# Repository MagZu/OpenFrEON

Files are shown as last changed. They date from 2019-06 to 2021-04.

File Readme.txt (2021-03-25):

The plan is to gradually promote adjustments:
1. Adjust the size of the buckle so that it can fit the gopro socket in the market. (Has been completed)
2. Add LeTV phone case. (During testing)
3. Adjust the structural defects of the mobile phone case. (under design)
4. Cancel the hardware. Use the wood structure to ensure the strength of the buckle. (To be started)

Shell introduction, hardware details and purchase link
http://www.openpilot.net/?thread-14.htm

In the folder
pedal
giraffe
leeco
oneplus
gopro
*old is officially owned by openfreon

All rights reserved by copyright owners

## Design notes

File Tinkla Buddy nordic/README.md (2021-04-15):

<h2>Print settings</h2>

layer height 0,2<br>
100% infill density<br>
Material: ABS<br>
Support: no<br>
<br>
I used wall thickness 1,5mm <br>
<br>
Feel free to ask me on discord (MagZu #3328) and I will share the project if you want to modify the case

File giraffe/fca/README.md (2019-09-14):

FCA (Fiat Chrysler Automotive) Giraffe
====

Get your panda deeper into your:

- 2017 Chrysler Pacifica Hybrid

May fit other FCA cars as well.

The switches
====

The 2 DIP switches control signals to the stock ADAS system

- 1 -- IGN to camera

- 2 -- ADAS CAN1 -> camera CAN (OBDII pins 12 & 13)



Initial design from the community from: [@adhintz](https://github.com/adhintz)

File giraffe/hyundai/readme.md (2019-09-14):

Hyundai giraffe
====

Get your panda deeper into your compatible Hyundai vehicle. Built with pinout for our Hyundai Sante Fe. May work with other Hyundai/Kia, check EWD for verification. 

The switches
====

The 4 DIP switches control signals to the stock ADAS system

- 1 -- ADAS CAN1 -> main body CAN

- 2 -- ADAS CAN1 -> panda CAN3 (OBDII pins 12 & 13)

- 3 -- IGNITION POWER -> panda power

- 4 -- ADAS power & ignition -> power & ignition

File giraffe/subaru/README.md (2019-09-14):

Subaru giraffe
====

Get your panda deeper into your Subaru Impreza
May work with other cars with the same connector

====

All switching between stock ADAS on and Stock ADAS off is done via a relay

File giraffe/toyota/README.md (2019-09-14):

Toyota giraffe
====

Get your panda deeper into your compatible Toyota vehicle

The switches
====



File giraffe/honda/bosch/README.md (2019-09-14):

Honda giraffe (Bosch ADAS)
====

Get your panda deeper into your:

- 2017+ Honda CR-V
- 2017+ Honda Civic Hatchback
- 2018+ Honda Accord

May fit other Hondas with Bosch hardware as well.

The switches
====

The 2 DIP switches control signals to the stock ADAS system

- 1 -- IGN to camera

- 2 -- ADAS CAN2 -> camera CAN (OBDII pins 12 & 13)



Initial design from the community from: [@csouers](https://github.com/csouers), [@energee](https://github.com/energee), and Alaric Egli

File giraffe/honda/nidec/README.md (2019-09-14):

Honda giraffe
====

Get your panda deeper into your Honda Civic or Acura ILX

The switches
====

The 4 DIP switches control signals to the stock ADAS system

- 1 -- ADAS CAN1 -> main body CAN

- 2 -- ADAS CAN1 -> panda CAN3 (OBDII pins 12 & 13)

- 3 -- ADAS CAN2 -> radar CAN

- 4 -- ADAS power & ignition -> power & ignition



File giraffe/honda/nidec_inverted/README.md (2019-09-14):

Honda Inverted Giraffe
====

Get your panda deeper into your Odyssey, 2019 Honda Pilot, TLX and probably other cars with an "inverted" connector

The switches
====

The 4 DIP switches control signals to the stock ADAS system

- 1 -- ADAS CAN1 -> main body CAN

- 2 -- ADAS CAN1 -> panda CAN3 (OBDII pins 12 & 13)

- 3 -- ADAS CAN2 -> radar CAN

- 4 -- ADAS power & ignition -> power & ignition



Thanks to [@csouers](https://github.com/csouers) and [@energee](https://github.com/energee) for their input on this design

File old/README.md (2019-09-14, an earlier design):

# OpenFrEON 2.0

This project is for the purpose of creating a device similar to Comma.ai's [EON DevKit](https://comma.ai/shop/products/eon-gold-dashcam-devkit/?ref=4). 

If you don't already have an EON DevKit, you can buy one here: [https://comma.ai/shop/products/eon-gold-dashcam-devkit](https://comma.ai/shop/products/eon-gold-dashcam-devkit/?ref=4)

Note: These components are designed to fit the dimensions the One Plus 3T smartphone. Other devices will not be compatible. 

FrEON2.0 Front
FrEON2.0 Back

# Printable—Included Parts

- FrEON2.stl (All parts for standard FrEON 2.0)

- FrEON2EM.stl (All parts for FrEON 2.0 modded for 140mm heatsink

**FrEON2-Components**

- FrEON2-Left.stl

- FrEON2-Right.stl

- FrEON2-FanDuct.stl

- FrEON2-BottomClip.stl

**FrEON2EM-Components (for 140mm heatsink)**

- FrEON2-Left.stl

- FrEON2-Right.stl

- FrEON2-BottomClip.stl

**Mounts**

- includes FrEON mounts from 20-40 degrees in increments of 2 degrees. 

# Non-Printable Parts & Hardware

- [4 x M3x10mm Screws](https://www.amazon.com/Uxcell-a16022300ux0165-M3x10mm-Socket-Countersunk/dp/B01DIL1KDS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)

- [4 x Heat Set Inserts](https://www.amazon.com/Uxcell-a16041800ux0824-Knurled-Threaded-Embedment/dp/B01IYWTCWW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)

- [100x60x10mm Heatsink](https://www.amazon.com/Heatsink-TOOGOO-Aluminum-Radiator-100x60x10mm/dp/B01EJ1CYB8) _(The Heatsink included with the EON **Dashcam Devkit** is milled to accommodate the camera lens.)_

- [40x10mm 5V Blower](https://www.digikey.com/product-detail/en/delta-electronics/BFB0405HHA-A/603-1113-ND/1014444) 

- [3M GoPro Mount](https://www.amazon.com/dp/B00BUD6LPY) 

# Support

If you have any questions regarding development or issues with the current design, find me on [Discord](https://discord.comma.ai/) _@Chase_

Help fund this project and future projects by donating via paypal: https://paypal.me/chasehiggins/

Or support me on patreon: https://www.patreon.com/chasehiggins/

Support Comma.ai and myself by buying an EON using my affiliate link: https://comma.ai/shop/?ref=4

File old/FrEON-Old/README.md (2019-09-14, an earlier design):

# OpenFrEON

Open Source parts to replace broken or damaged pieces on your existing **EON Dashcam DevKit** from [Comma.ai](http://comma.ai).

If you don't already have an EON Dashcam DevKit, you can buy one here: [https://comma.ai/shop/products/eon-dashcam-devkit/](https://comma.ai/shop/products/eon-dashcam-devkit/?ref=4)

FrEON

# Printable—Included Parts

- FrEON Body Left

- FrEON Body Right

- FrEON Bottom Clip

- FrEON Fan Cover Grill

- Fake Heatsink

# Printable—not-included Parts

The only printed pieces not included in this repository are the various degree mounting clips—these parts can be found on [Comma.ai's GitHub](https://github.com/commaai/neo/tree/master/case/eon). 

# Non-Printable Parts & Hardware

- [8 x M3x6mm screws](https://www.amazon.com/dp/B079821FCN/ref=twister_B079838C8T?_encoding=UTF8&psc=1)

- [8 x M3 Nuts](https://www.amazon.com/Shapenty-100PCS-Stainless-Female-Fastener/dp/B071NLDW56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)

- [100x60x10mm Heatsink](https://www.amazon.com/Heatsink-TOOGOO-Aluminum-Radiator-100x60x10mm/dp/B01EJ1CYB8) _(The Heatsink included with the EON **Dashcam Devkit** is milled to accommodate the camera lens.)_

- [40x10mm 5V Blower](https://www.digikey.com/product-detail/en/delta-electronics/BFB0405HHA-A/603-1113-ND/1014444) 

- [3M GoPro Mount](https://www.amazon.com/dp/B00BUD6LPY) 

# ToDo

- [x] Design _Left_ and _Right_ portions of FrEON housing

- [x] Design Bottom Clip

- [x] Compile a list of parts and pieces

- [x] Design Fan Cover

- [ ] Accommodate space for EON Board

- [ ] Peltier Version

- [ ] Custom FrEON Board

# Support

If you have any questions regarding development or issues with the current design, find me on [Slack](comma.slack.com) _@Chase_

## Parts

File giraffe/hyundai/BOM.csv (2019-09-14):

Ref Des | Package | Manufacturer PN | Qty | Link
U1 | 12-Pin | MG645845 | 1 | https://chcwld.en.alibaba.com/product/60784996669-801836231/KET_020_12M_Automotive_cable_connector_Electronic_Connector.html
U2 | 12-Pin | MG655794 | 1 | https://chcwld.en.alibaba.com/product/60784830234-801836231/KET_020_12F_Automotive_cable_connector_Electronic_Connector.html
 |  | ST731407-3 | 12
J1 | 16-pin | OBDII-FEMALE | 1 | https://cn1514770021qfbj.en.alibaba.com/product/60598699808-804284542/J1962F_OBD2_16_Pin_Female_connector_OBD2_Socket.html
J2 | RJ45-RA | A-2004-2-4-LPS-N-R | 1 | https://www.digikey.com/product-detail/en/assmann-wsw-components/A-2004-2-4-LPS-N-R/AE10387-ND/2183638
J3 | 3-pin | EJ508A | 1 | https://www.digikey.com/products/en?keywords=ej508a
SW1 | SMD | 204-214ST | 1 | https://www.digikey.com/scripts/DkSearch/dksus.dll?Detail&itemSeq=238874105&uq=636415194298612120
R1 | 0603-R | ERJ-PA3J121V | 1 | https://www.digikey.com/product-detail/en/panasonic-electronic-components/ERJ-PA3J121V/P120BZCT-ND/5036246

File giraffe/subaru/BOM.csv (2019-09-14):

Comma Access Point
Ref Des | Package | Manufacture PN | Qty | Link
J1 | 26 Pin R/A | 5018762640 | 1 | https://www.digikey.com/product-detail/en/molex/501876-2640/WM6091-ND/1787792
J2 | 10 Pin R/A | 5018761040 | 1 | https://www.digikey.com/products/en?keywords=501876-1040
J3 | 2 Pin R/A | 3-794618-2 | 1 | https://www.digikey.com/product-detail/en/te-connectivity-amp-connectors/3-794618-2/A33252-ND/1114990
R1 | DNP | DNP | DNP
R2 | R0402 | ERJ-2GEJ121X | 1 | https://www.digikey.com/product-detail/en/panasonic-electronic-components/ERJ-2GEJ121X/P120JCT-ND/146744
R4 | R0402 | ERJ-2GE0R00X | 1 | https://www.digikey.com/product-detail/en/panasonic-electronic-components/ERJ-2GEJ121X/P120JCT-ND/146744
C1 | DNP | DNP | DNP
S1 |  | G6S-2G DC12 | 1 | https://www.digikey.com/product-detail/en/omron-electronics-inc-emc-div/G6S-2G-DC12/Z892-ND/20450
D1,D2 | SMD | ES2BA-13-F | 1 | https://www.digikey.com/product-detail/en/diodes-incorporated/ES2BA-13-F/ES2BA-FDICT-ND/815690
Panda Interface Point
Ref Des | Package | Manufacture PN | Qty | Link
J1 | OBDII |  | 1 | https://cn1514770021qfbj.en.alibaba.com/product/60598699808-804284542/J1962F_OBD2_16_Pin_Female_connector_OBD2_Socket.html
J2 | RJ45 R/A | A-2004-2-4-LPS-N-R | 1 | https://www.digikey.com/product-detail/en/assmann-wsw-components/A-2004-2-4-LPS-N-R/AE10387-ND/2183638
J3 | 10 Pin R/A | 5018761040 | 1 | https://www.digikey.com/products/en?keywords=501876-1040
Wiring Harness
Ref Des | Package | Manufacture PN | Qty | Link
 | 10 Pin Female | 5016461000 | 2 | https://www.digikey.com/product-detail/en/molex/5016461000/WM6058-ND/1787759
 | 26 Pin Female | 5016462600 | 1 | https://www.digikey.com/short/ppwt0m
 | Molex Crimp Pins | 5016471000 | 44 | https://www.digikey.com/product-detail/en/molex/5016471000/WM6057CT-ND/1787797
 | 16 Pin Male | 1565476-1 | 1 | https://www.mouser.com/ProductDetail/TE-Connectivity/1565476-1
 | 16 Pin Female | 1318386-1 | 1 | https://www.digikey.com/product-detail/en/te-connectivity-amp-connectors/1318386-1/A106550-ND/2273493
 | TE Connectivity crimp pins | 1123343-1 | 24 | https://www.digikey.com/product-detail/en/te-connectivity-amp-connectors/1123343-1/A107011CT-ND/3488572

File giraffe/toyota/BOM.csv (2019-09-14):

Ref Des | Package | Manufacturer PN | Qty | Link
J1 | 12-pin | 1318774-1 | 1 | http://www.mouser.com/Search/ProductDetail.aspx?R=1318774-1virtualkey57100000virtualkey571-1318774-1
J2 | 12-pin-RA | 1318772-2 | 1 | http://www.mouser.com/Search/ProductDetail.aspx?R=1318772-2virtualkey57100000virtualkey571-1318772-2
 |  | 1123343-1 | 12 | https://www.digikey.com/product-detail/en/te-connectivity-amp-connectors/1123343-1/A107011CT-ND/3488572
 |  | PRPC040SAAN-RC | 1 | https://www.digikey.com/products/en?keywords=S1011EC-40-ND
J3 | 16-pin | OBDII-FEMALE | 1 | https://cn1514770021qfbj.en.alibaba.com/product/60598699808-804284542/J1962F_OBD2_16_Pin_Female_connector_OBD2_Socket.html
J4 | RJ45-RA | A-2004-2-4-LPS-N-R | 1 | https://www.digikey.com/product-detail/en/assmann-wsw-components/A-2004-2-4-LPS-N-R/AE10387-ND/2183638
J5 | 3-pin | EJ508A | 1 | https://www.digikey.com/products/en?keywords=ej508a
SW1 | SMD | 204-214ST | 1 | https://www.digikey.com/scripts/DkSearch/dksus.dll?Detail&itemSeq=238874105&uq=636415194298612120
R1 | 0603 | ERJ-PA3F1200V | 1 | https://www.digikey.com/short/p47rhj
SCREWs | Phillips | 92010A118 | 2 | https://www.mcmaster.com/#catalog/92010A118

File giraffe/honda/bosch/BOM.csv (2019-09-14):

Ref Des | Package | MPN | Qty | Link
J3 | 12-pin | OBDII-FEMALE | 1 | https://www.alibaba.com/product-detail/J1962F-OBD2-OBD-2-16-Pin_60657250485.html
SW1 | SMD | CT204212ST-ND | 1 | https://www.digikey.com/products/en?mpart=204-212ST&v=119
J1 | 3-pin | EJ508A-ND | 1 | https://www.digikey.com/products/en?keywords=ej508a
J4 | RJ45-VERT | AE10399-ND | 1 | https://www.digikey.com/scripts/DkSearch/dksus.dll?Detail&itemSeq=265472924&uq=636662223909317983
J5 | 12 Pin | M34S75C4F1 | 12 | https://www.digikey.com/product-detail/en/jae-electronics/M34S75C4F1/670-2268-2-ND/2044176
J2 | 12 Pin | S1211EC-40-ND | 12 | https://www.digikey.com/product-detail/en/sullins-connector-solutions/PRPC040SFAN-RC/S1211EC-40-ND/2775334
D1 | SMD | ES2BA-13-F | 1 | https://www.digikey.com/product-detail/en/diodes-incorporated/ES2BA-13-F/ES2BA-FDICT-ND/815690
M3 8mm | Hex | 91294A132 | 1 | https://www.mcmaster.com/#91294A128
M3 14 mm | Hex | 91294A128 | 2 | https://www.mcmaster.com/#91294A133
Nut | Hex | 91828A211 | 2 | https://www.mcmaster.com/#catalog/124/3276/=1doa85x

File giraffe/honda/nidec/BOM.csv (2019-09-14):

Ref Des | Package | Manufacturer PN | Qty | Link
J1 | 20-pin-RA | MX34020NF1 | 1 | https://www.digikey.com/product-detail/en/jae-electronics/MX34020NF1/670-2924-ND/2139260
J2 | 20-pin | MX34020SF1 | 1 | https://www.digikey.com/scripts/DkSearch/dksus.dll?Detail&itemSeq=238973409&uq=636415194298622122
 |  | M34S75C4F1 | 20 | https://www.digikey.com/product-detail/en/jae-electronics/M34S75C4F1/670-2268-1-ND/2044290
 |  | PRPC040SAAN-RC | 1 | https://www.digikey.com/products/en?keywords=S1011EC-40-ND
J3 | 16-pin | OBDII-FEMALE | 1 | https://cn1514770021qfbj.en.alibaba.com/product/60598699808-804284542/J1962F_OBD2_16_Pin_Female_connector_OBD2_Socket.html
J4 | RJ45-VERT | A-2014-2-4-LP/FS-R | 1 | https://www.digikey.com/scripts/DkSearch/dksus.dll?Detail&itemSeq=238773681&uq=636415194298592116
SW1 | SMD | 204-214ST | 1 | https://www.digikey.com/scripts/DkSearch/dksus.dll?Detail&itemSeq=238874105&uq=636415194298612120
SCREWs | Phillips | 92010A118 | 2 | https://www.mcmaster.com/#catalog/92010A118

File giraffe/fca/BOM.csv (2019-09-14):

Ref Des | Package | MPN | Qty | Link
J1 | 3-pin | RASM722PX | 1 | https://www.digikey.com/products/en?keywords=RASM722PX
J2 | OBDII | J1962F | 1 | https://www.alibaba.com/product-detail/J1962F-OBD2-OBD-2-16-Pin_60657250485.html
J3 | RJ45-RA | A-2004-2-4-LPS-N-R | 1 | https://www.digikey.com/product-detail/en/assmann-wsw-components/A-2004-2-4-LPS-N-R/AE10387-ND/2183638
J4 | CONN HEADER VERT | 348250124 | 1 | https://www.digikey.com/product-detail/en/0348250124/WM10326-ND/4504599/?itemSeq=281019679
J5 | MINI50 CONN RCPT | 348240124 | 1 | https://www.digikey.com/product-detail/en/molex-llc/0348240124/WM10324-ND/4504597
SW1 | SMD | CT204212ST-ND | 1 | https://www.digikey.com/products/en?mpart=204-212ST&v=119
D1 | SMD | ES2BA-13-F | 1 | https://www.digikey.com/product-detail/en/diodes-incorporated/ES2BA-13-F/ES2BA-FDICT-ND/815690
R1 | 0603R | ERJ-PA3J121V | 1 | https://www.digikey.com/product-detail/en/panasonic-electronic-components/ERJ-PA3J121V/P120BZCT-ND/5036246
Crimps |  | 5600230421 | 12 | https://www.digikey.com/product-detail/en/molex-llc/5600230421/WM8745CT-ND/3178491
Pins | S1011EC-40-ND |  | 12 | https://www.digikey.com/products/en?keywords=S1011EC-40-ND

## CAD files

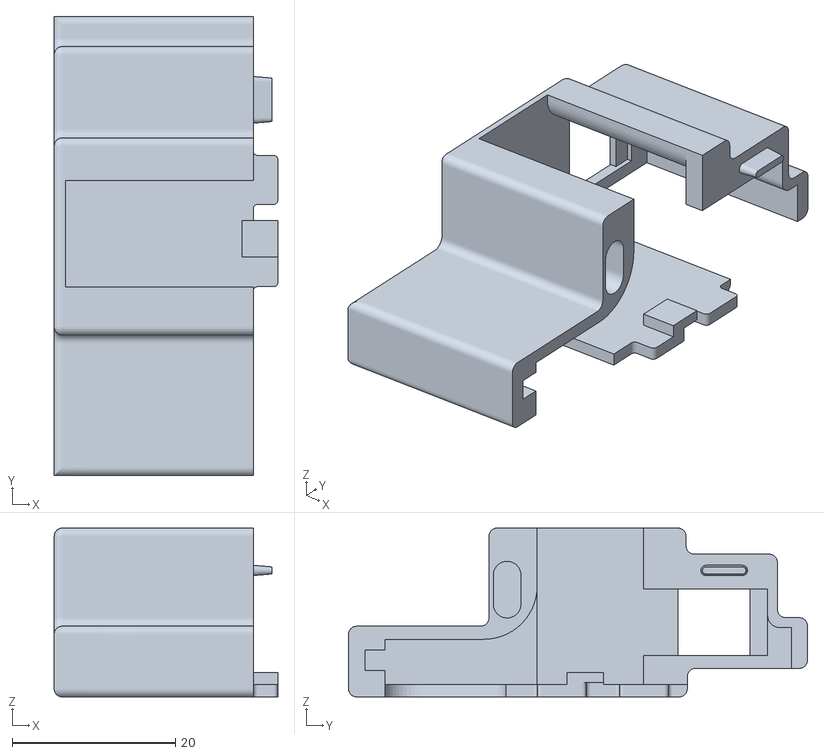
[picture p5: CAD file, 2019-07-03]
giraffe/fca/Giraffe_left.stl
27.4 x 56.2 x 20.7

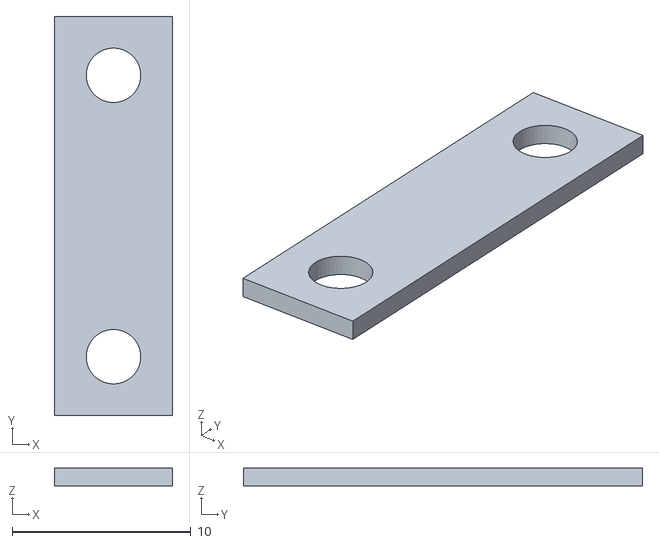
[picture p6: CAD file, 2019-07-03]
giraffe/ford/mechanical/giraffe_ford_spacer.stl
6.60 x 22.4 x 1.00

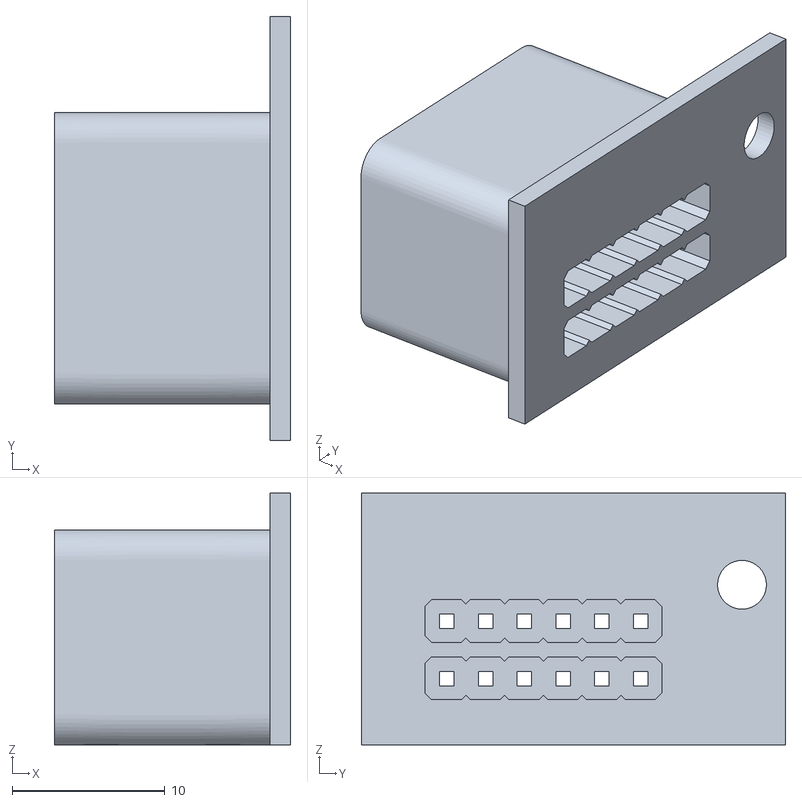
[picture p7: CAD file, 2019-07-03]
giraffe/honda/bosch/bosch_female_connector.stl
15.5 x 27.8 x 16.5

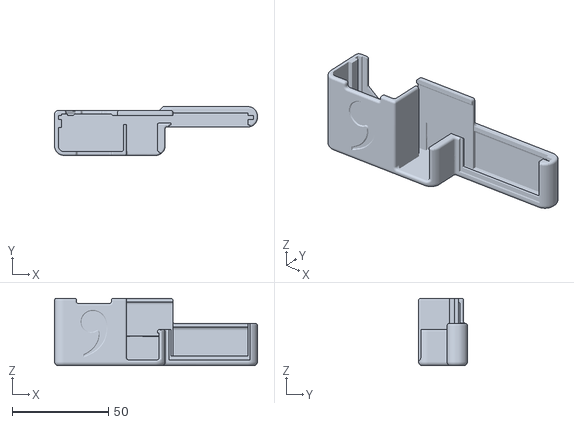
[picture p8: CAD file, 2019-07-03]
giraffe/honda/nidec/case.stl
105.5 x 25.4 x 35.0

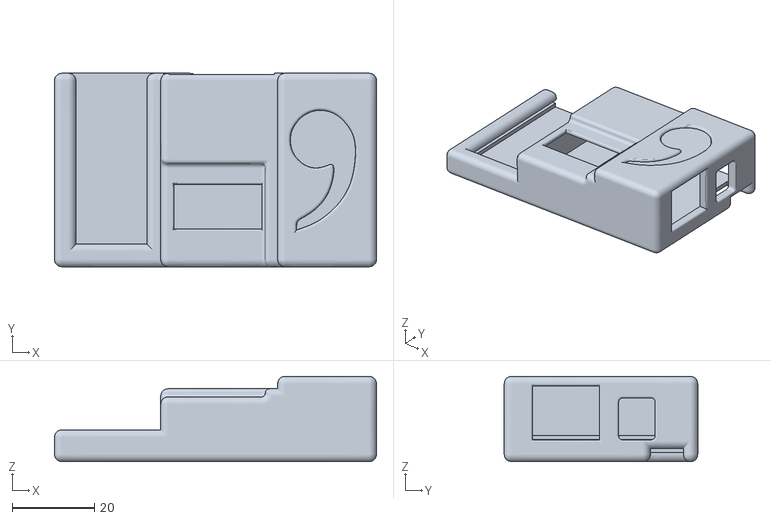
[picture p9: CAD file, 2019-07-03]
giraffe/hyundai/Hyundai_Giraffe.stl
78.2 x 47.0 x 20.7

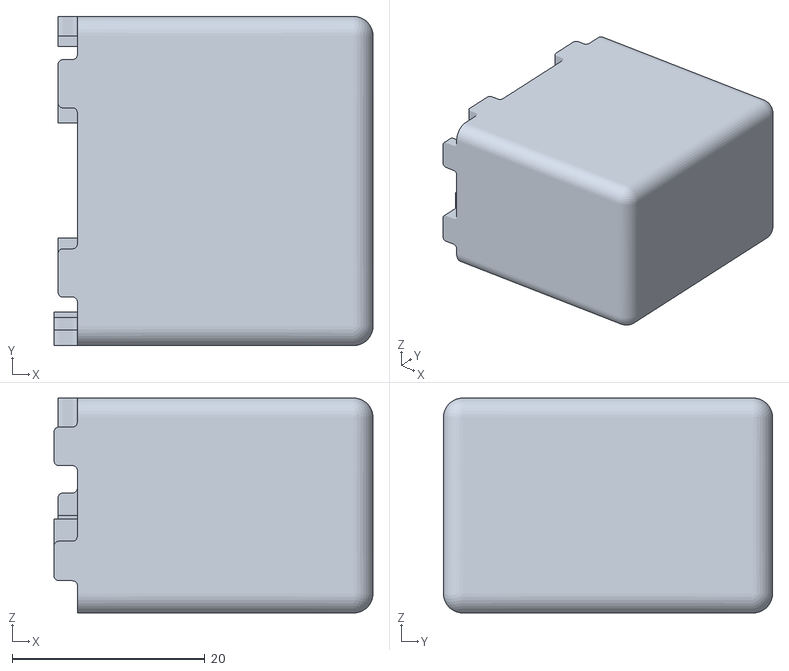
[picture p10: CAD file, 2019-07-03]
giraffe/subaru/PIP_right.stl
33.1 x 34.1 x 22.3

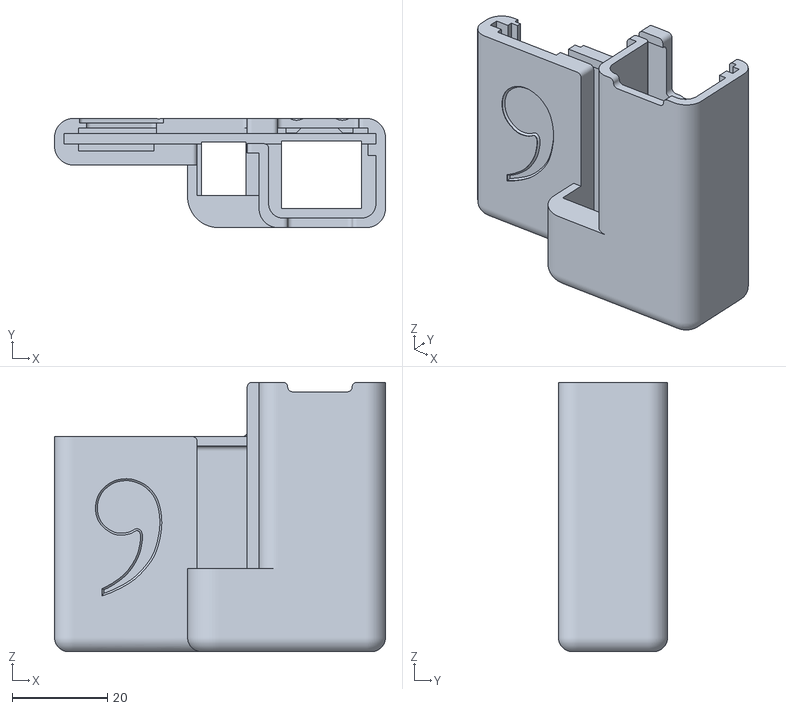
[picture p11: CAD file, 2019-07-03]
giraffe/toyota/case.stl
69.4 x 22.9 x 56.5

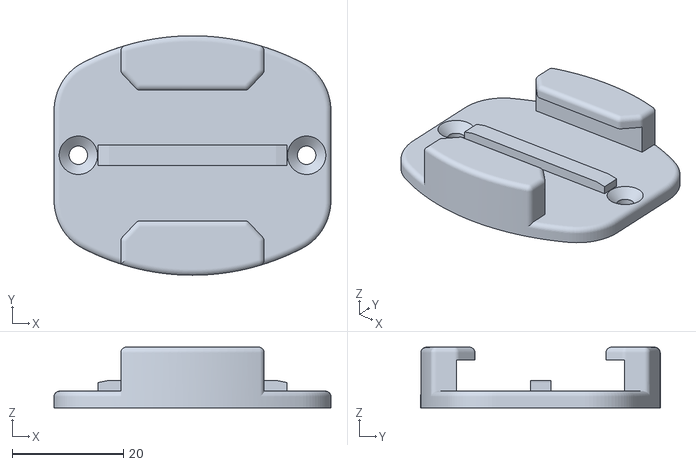
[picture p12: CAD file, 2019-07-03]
gopro mount/gopro.STL
49.8 x 43.0 x 10.9

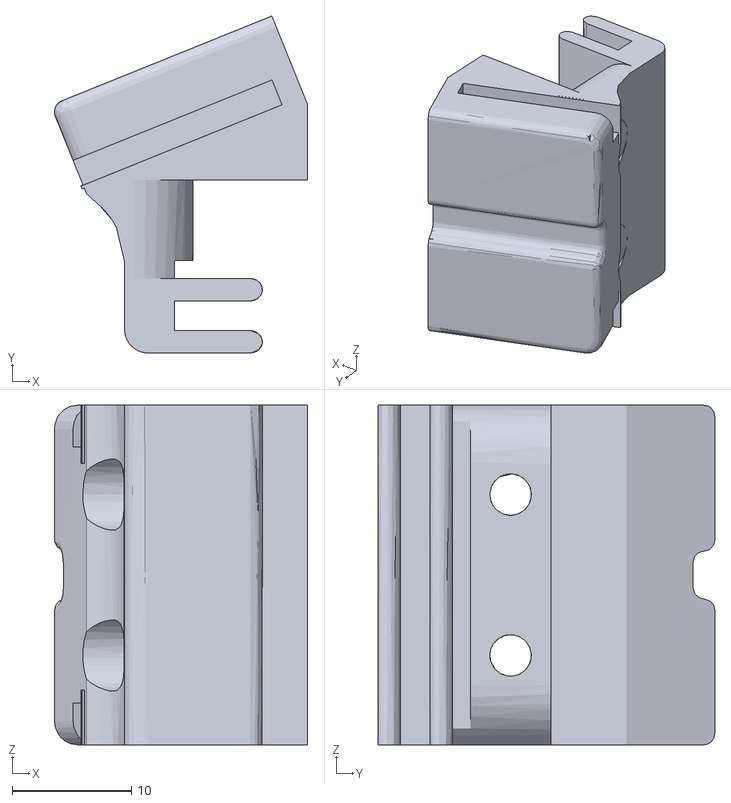
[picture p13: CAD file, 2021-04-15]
leeco lepro3 x720/Tesla mount 22D_2.15mm_slot.stl
21.2 x 28.3 x 28.5

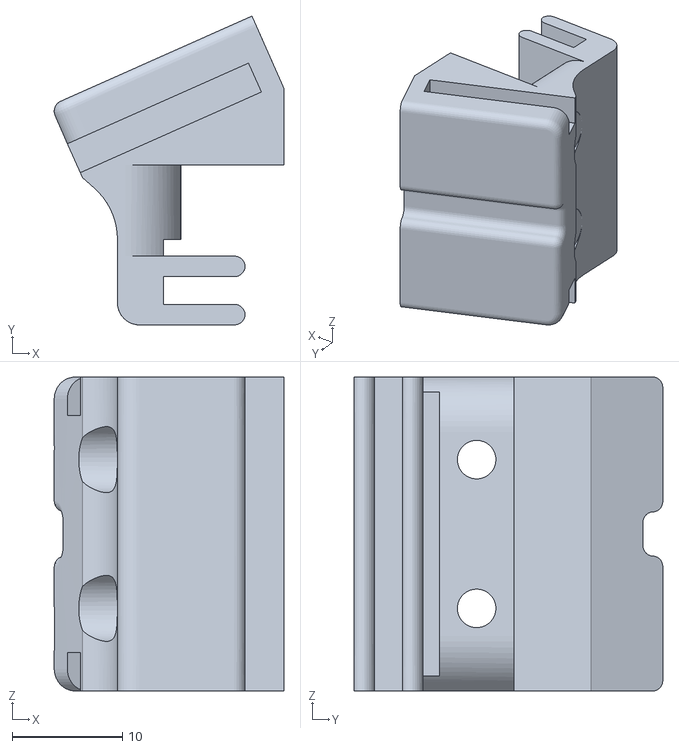
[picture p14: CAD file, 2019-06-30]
oneplus 3t/修改版挂钩.STL
20.8 x 28.0 x 28.5

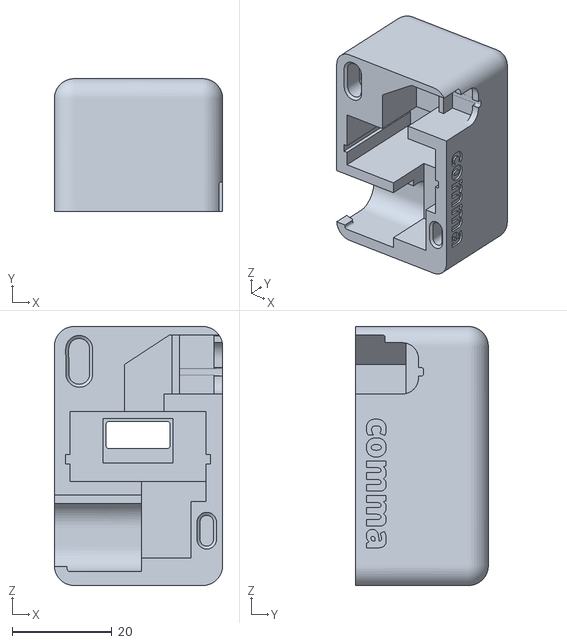
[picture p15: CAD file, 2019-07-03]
pedal/comma.stl
33.8 x 26.6 x 52.0

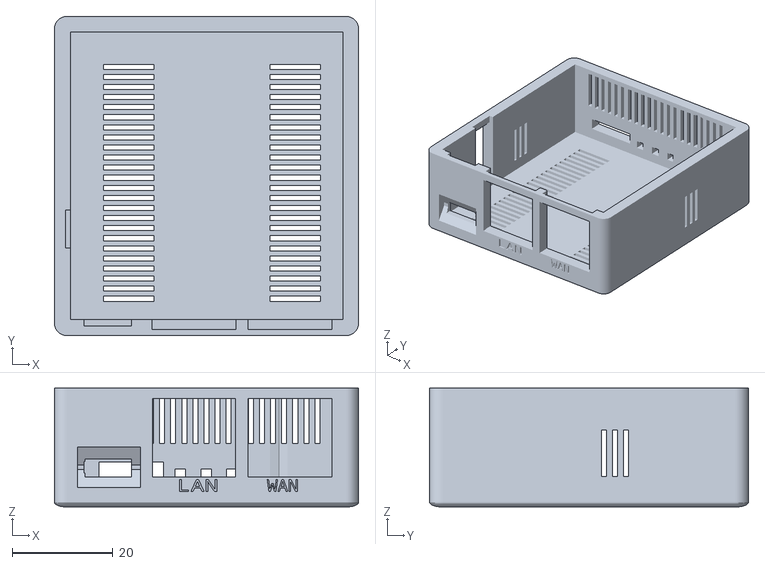
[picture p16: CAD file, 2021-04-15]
Tinkla Buddy nordic/Tinkla Buddy Nordic_bottom v08.stl
60.4 x 63.3 x 23.6

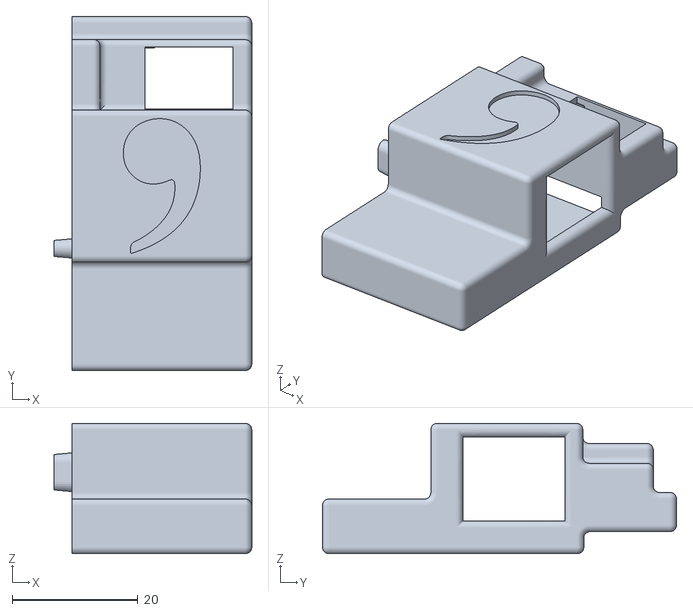
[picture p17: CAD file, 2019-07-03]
giraffe/fca/Giraffe_right.stl
31.4 x 56.2 x 20.7

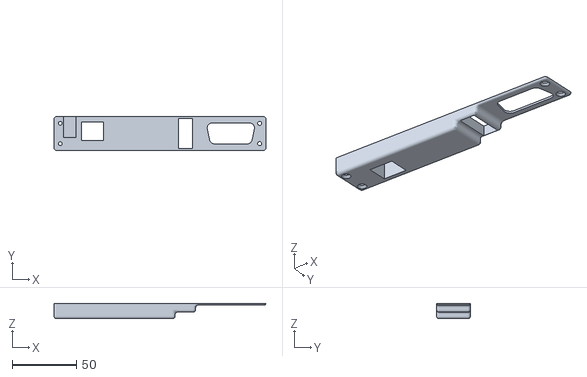
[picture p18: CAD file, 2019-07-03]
giraffe/ford/mechanical/giraffe_ford_top.stl
164.5 x 26.4 x 11.9

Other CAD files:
giraffe/honda/nidec_inverted/case.stl
giraffe/honda/bosch/bosch_male.stl
giraffe/subaru/PIP_left.stl
gopro mount/gopro2.STL
Tinkla Buddy nordic/Tinkla Buddy Nordic_top v12.stl
giraffe/ford/mechanical/giraffe_ford_bottom.stl
giraffe/honda/bosch/bosch_back.stl
giraffe/honda/bosch/bosch_front.stl
leeco lepro3 x720/BottomClip.stl
leeco lepro3 x720/Left Case.STL
leeco lepro3 x720/Original gopro mount.stl
leeco lepro3 x720/Right Case.STL
old/FrEON-Old/FrEON Bottom Clip.stl
old/FrEON-Old/FrEON Fake Heatsink.stl
old/FrEON-Old/FrEON Fan Shield.stl
old/FrEON-Old/FrEON Left.stl
old/FrEON-Old/FrEON Right.stl
old/FrEON2-Components/FrEON2-FanDuct.stl
old/FrEON2-Components/FrEON2-Left.stl
old/FrEON2-Components/FrEON2-Right.stl
old/FrEON2.stl
old/FrEON2EM.stl
old/Mounts/20degMountF2.stl
old/Mounts/22degMountF2.stl
old/Mounts/26degMountF2.stl
old/Mounts/28degMountF2.stl
old/Mounts/30degMountF2.stl
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

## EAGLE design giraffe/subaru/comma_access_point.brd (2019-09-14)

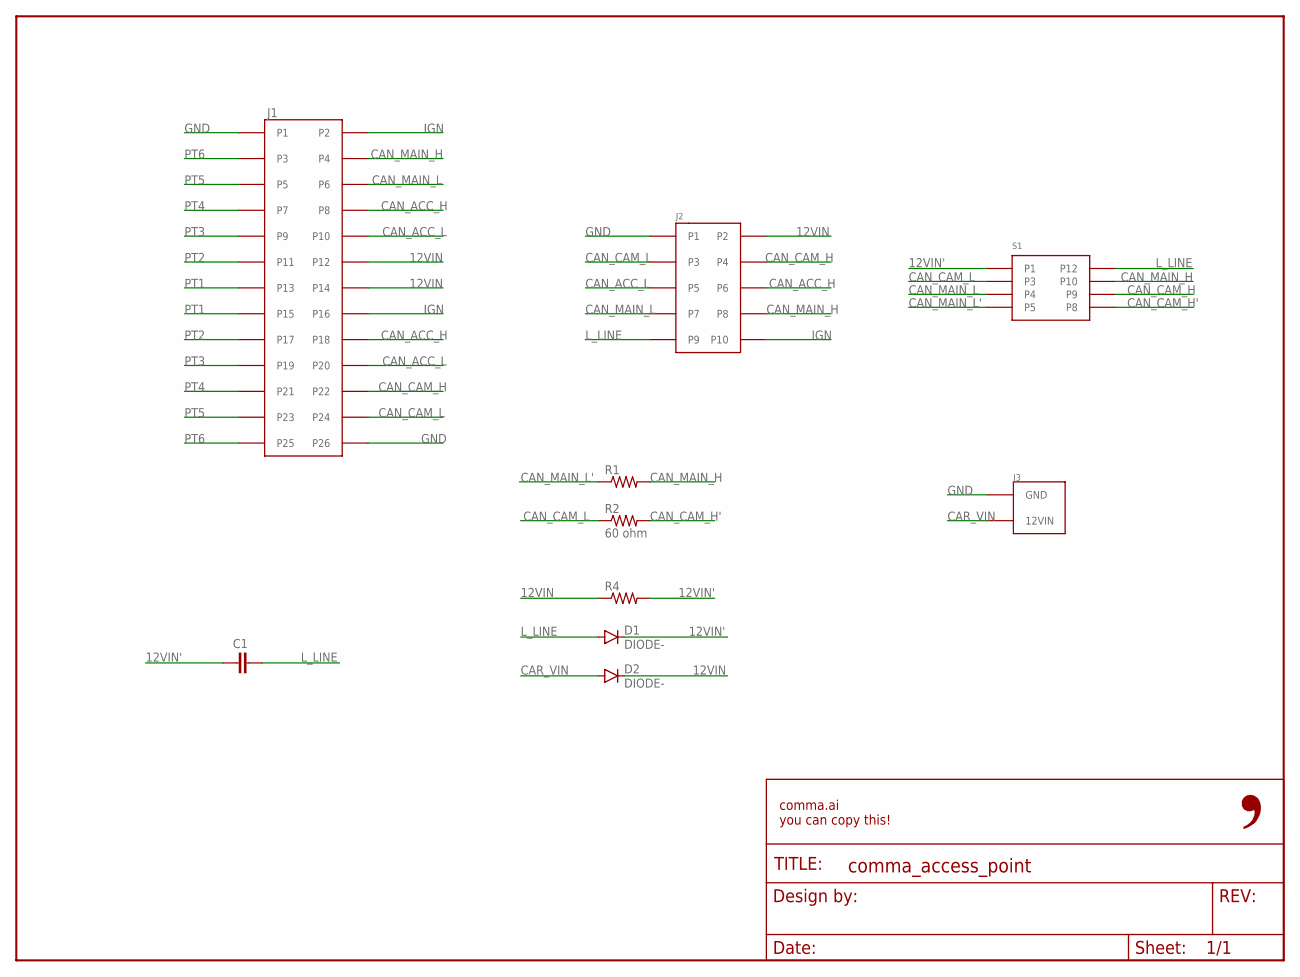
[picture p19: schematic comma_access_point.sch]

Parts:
C1: C0805; 0805-C
D1, D2: DIODE-; DO-214
FRAME1: FRAME-LETTER-OPENNO_PACKAGE; DUMMY
J1: 5018762640
J2: 5018761040
J3: 3-794618-2
R1, R4: R0402; 0402-R
R2: 60 ohm; 0402-R
S1: G6S-2G-DC12; G6S-26-DC12

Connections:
12VIN: D2.1 (C), J1.P12, J1.P14, J2.P2, R4.1
12VIN': C1.1, D1.1 (C), R4.2, S1.P1
CAN_ACC_H: J1.P8, J1.P18, J2.P6
CAN_ACC_L: J1.P10, J1.P20, J2.P5
CAN_CAM_H: J1.P22, J2.P4, S1.P9
CAN_CAM_H': R2.2, S1.P8
CAN_CAM_L: J1.P24, J2.P3, R2.1, S1.P3
CAN_MAIN_H: J1.P4, J2.P8, R1.2, S1.P10
CAN_MAIN_L: J1.P6, J2.P7, S1.P4
CAN_MAIN_L': R1.1, S1.P5
CAR_VIN: D2.2 (A), J3.12VIN
GND: J1.P1, J1.P26, J2.P1, J3.GND
IGN: J1.P2, J1.P16, J2.P10
L_LINE: C1.2, D1.2 (A), J2.P9, S1.P12
PT1: J1.P13, J1.P15
PT2: J1.P11, J1.P17
PT3: J1.P9, J1.P19
PT4: J1.P7, J1.P21
PT5: J1.P5, J1.P23
PT6: J1.P3, J1.P25

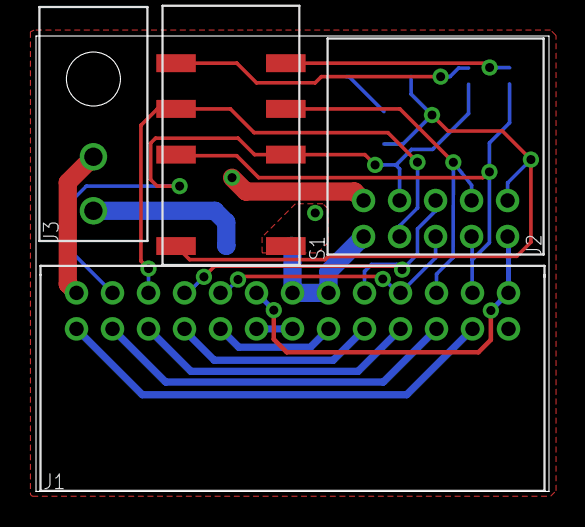
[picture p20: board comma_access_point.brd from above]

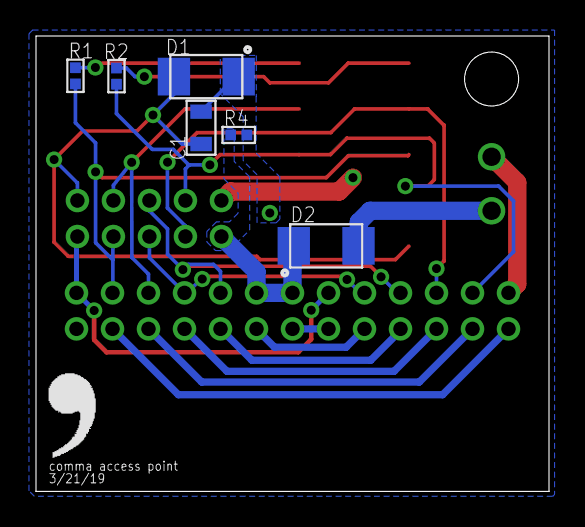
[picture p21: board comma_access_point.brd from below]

Board: 2 copper layers, 28.5 x 25.3 mm, 12 parts (7 on the bottom side), 20 nets.

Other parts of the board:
U$1: LOGO

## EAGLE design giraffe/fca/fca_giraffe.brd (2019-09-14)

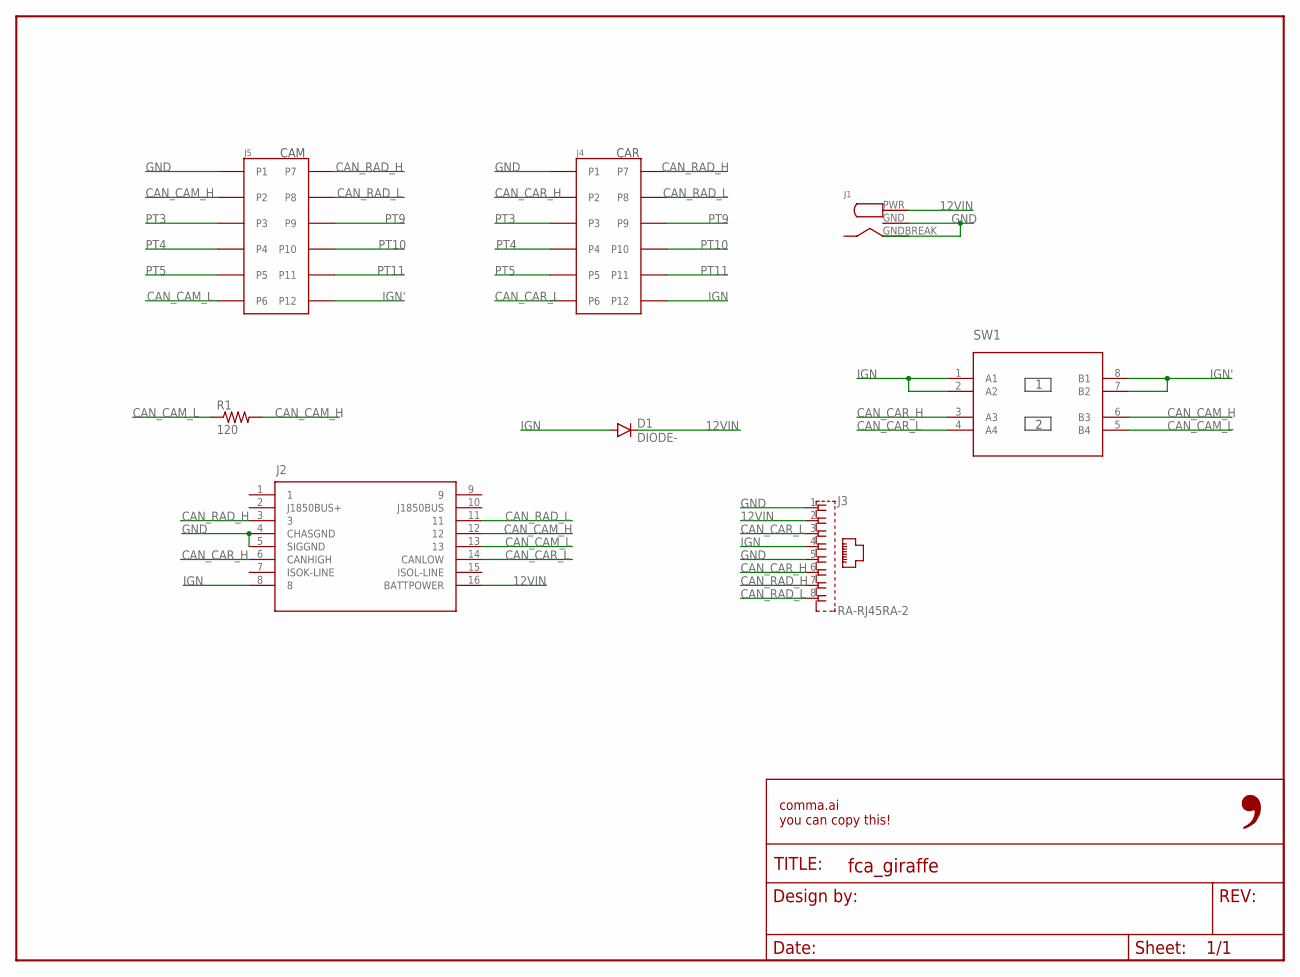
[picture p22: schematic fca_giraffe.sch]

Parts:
D1: DIODE-; DO-214
FRAME1: FRAME-LETTER-OPENNO_PACKAGE; DUMMY
J1: RASM722PX
J2: OBDII-FEMALE-CUT; OBDII-FEMALE-MIDCUT
J3: RA-RJ45RA-2; RA-RJ45-2
J4: 0348250124
J5: 0348240124
R1: 120; 0603-R
SW1: 2XDPST-CTS; 2-DPST

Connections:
12VIN: D1.1 (C), J1.PWR (12VIN), J2.16 (BATTPOWER), J3.2
CAN_CAM_H: J2.12, J5.P2, R1.2, SW1.6 (B3)
CAN_CAM_L: J2.13, J5.P6, R1.1, SW1.5 (B4)
CAN_CAR_H: J2.6 (CANHIGH), J3.6, J4.P2, SW1.3 (A3)
CAN_CAR_L: J2.14 (CANLOW), J3.3, J4.P6, SW1.4 (A4)
CAN_RAD_H: J2.3, J3.7, J4.P7, J5.P7
CAN_RAD_L: J2.11, J3.8, J4.P8, J5.P8
GND: J1.GND, J1.GNDBREAK, J2.4 (CHASGND), J2.5 (SIGGND), J3.1, J3.5, J4.P1, J5.P1
IGN: D1.2 (A), J2.8, J3.4, J4.P12, SW1.1 (A1), SW1.2 (A2)
IGN': J5.P12, SW1.7 (B2), SW1.8 (B1)
PT3: J4.P3, J5.P3
PT4: J4.P4, J5.P4
PT5: J4.P5, J5.P5
PT9: J4.P9, J5.P9
PT10: J4.P10, J5.P10
PT11: J4.P11, J5.P11

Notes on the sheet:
CAR
CAM

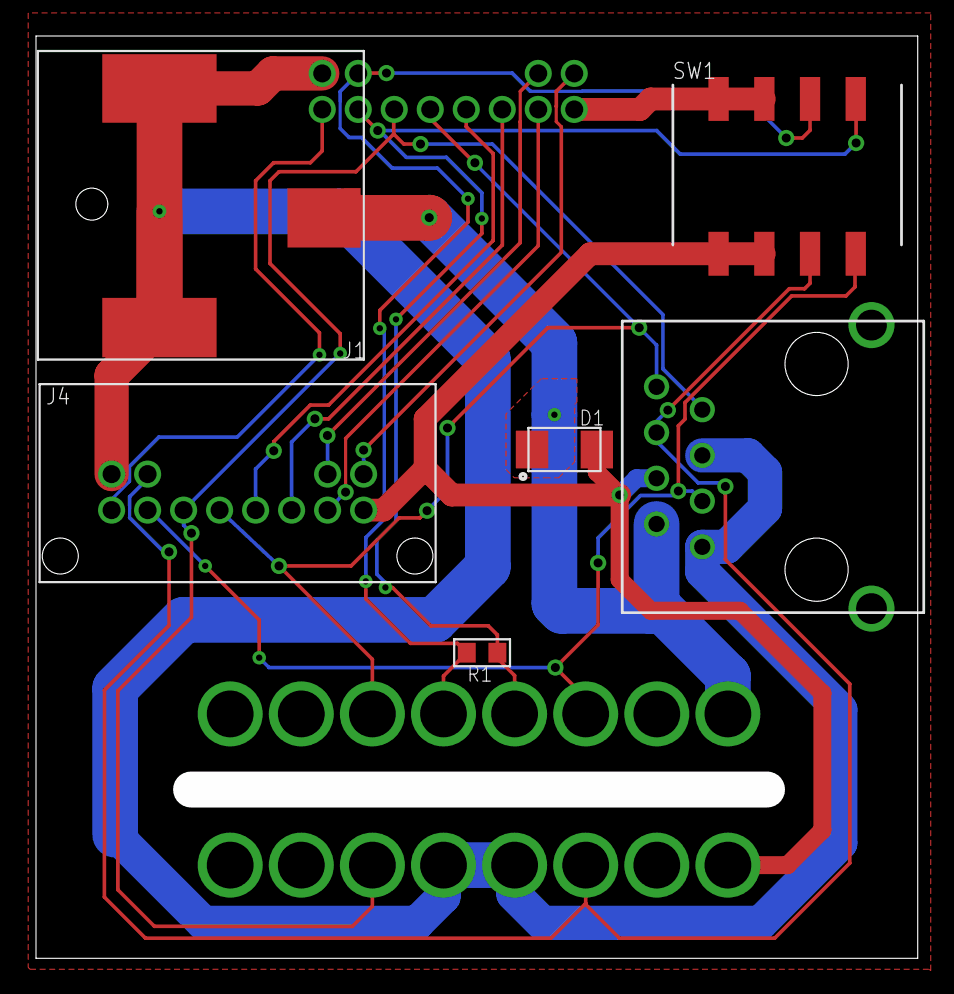
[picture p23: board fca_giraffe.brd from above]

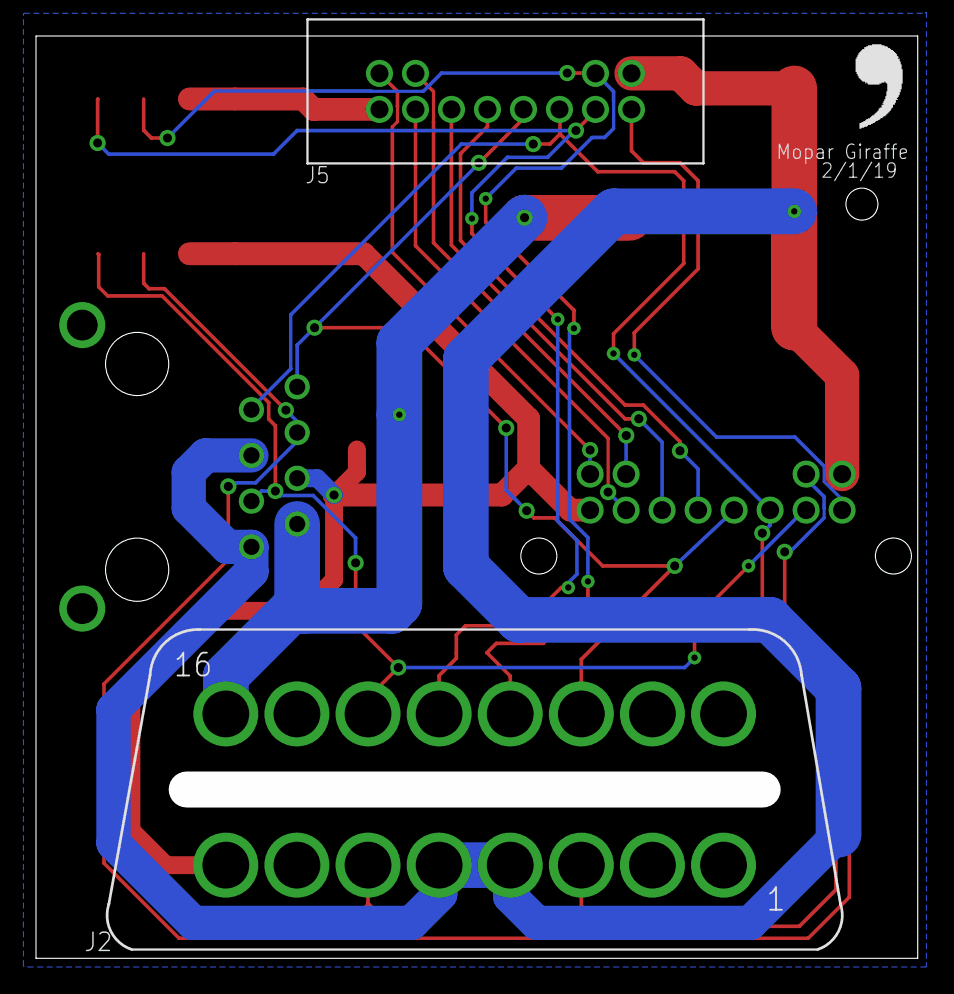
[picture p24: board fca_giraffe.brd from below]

Board: 2 copper layers, 49.0 x 51.2 mm, 10 parts (3 on the bottom side), 16 nets.

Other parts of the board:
U$1: LOGO

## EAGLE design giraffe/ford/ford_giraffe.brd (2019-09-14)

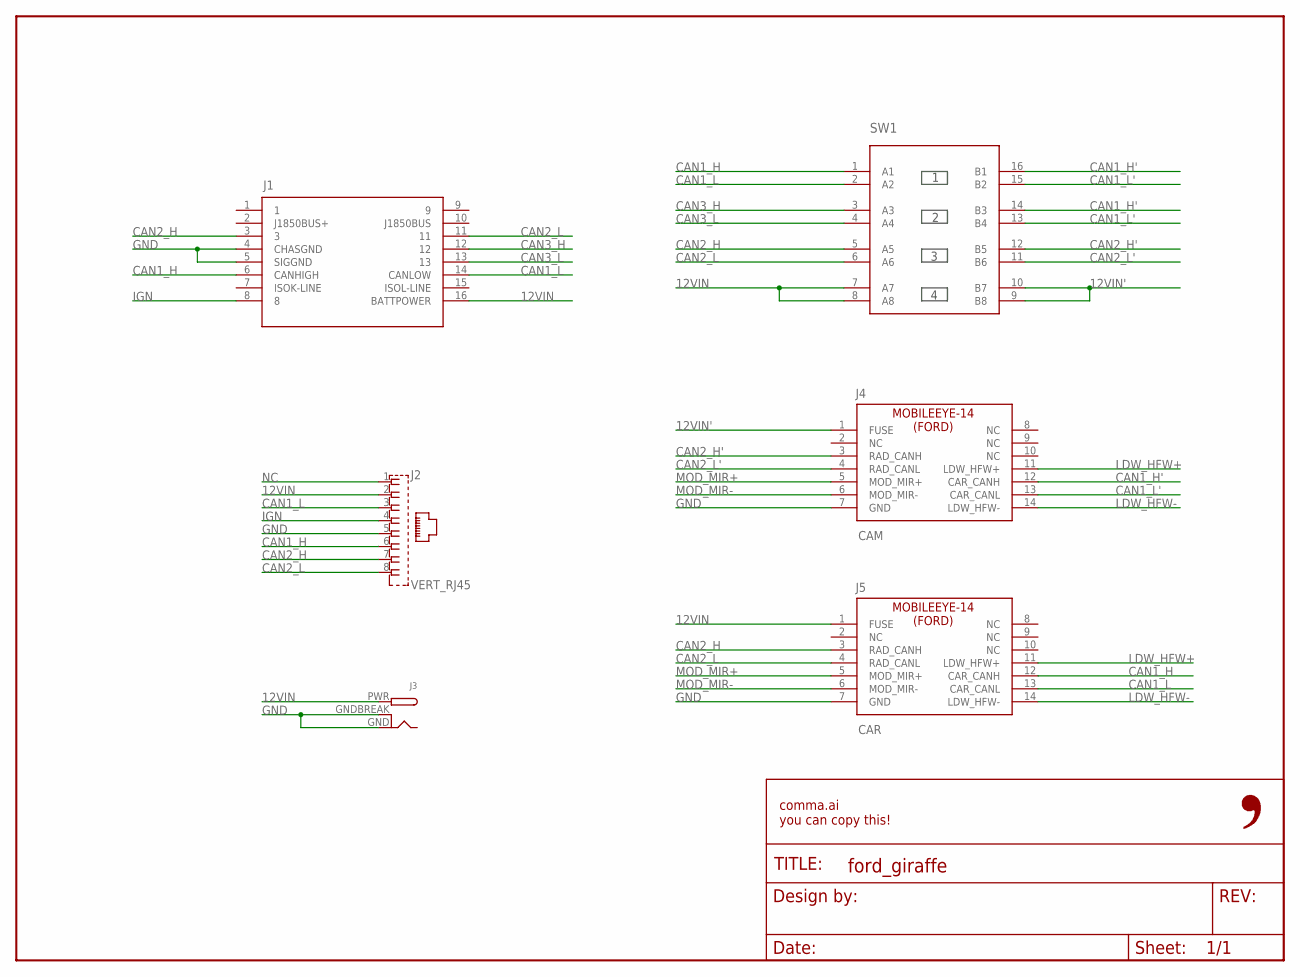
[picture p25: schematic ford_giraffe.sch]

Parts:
FRAME1: FRAME-LETTER-OPENNO_PACKAGE; DUMMY
J1: OBDII-FEMALE-CUT; OBDII-FEMALE-MIDCUT
J2: VERT_RJ45; GLX-S-88M
J3: DCBARRELPTH; DCJACK_2MM_PTH
J4: CAM; 2X7-FORD-CAR
J5: CAR; 2X7-FORD-CAM
SW1: 4XDPSTSMT; 4-DPST

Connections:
12VIN: J1.16 (BATTPOWER), J2.2, J3.PWR, J5.1 (FUSE), SW1.7 (A7), SW1.8 (A8)
12VIN': J4.1 (FUSE), SW1.9 (B8), SW1.10 (B7)
CAN1_H: J1.6 (CANHIGH), J2.6, J5.12 (CAR_CANH), SW1.1 (A1)
CAN1_H': J4.12 (CAR_CANH), SW1.14 (B3), SW1.16 (B1)
CAN1_L: J1.14 (CANLOW), J2.3, J5.13 (CAR_CANL), SW1.2 (A2)
CAN1_L': J4.13 (CAR_CANL), SW1.13 (B4), SW1.15 (B2)
CAN2_H: J1.3, J2.7, J5.3 (RAD_CANH), SW1.5 (A5)
CAN2_H': J4.3 (RAD_CANH), SW1.12 (B5)
CAN2_L: J1.11, J2.8, J5.4 (RAD_CANL), SW1.6 (A6)
CAN2_L': J4.4 (RAD_CANL), SW1.11 (B6)
CAN3_H: J1.12, SW1.3 (A3)
CAN3_L: J1.13, SW1.4 (A4)
GND: J1.4 (CHASGND), J1.5 (SIGGND), J2.5, J3.GND, J3.GNDBREAK, J4.7 (GND), J5.7 (GND)
IGN: J1.8, J2.4
LDW_HFW+: J4.11 (LDW_HFW+), J5.11 (LDW_HFW+)
LDW_HFW-: J4.14 (LDW_HFW-), J5.14 (LDW_HFW-)
MOD_MIR+: J4.5 (MOD_MIR+), J5.5 (MOD_MIR+)
MOD_MIR-: J4.6 (MOD_MIR-), J5.6 (MOD_MIR-)
NC: J2.1

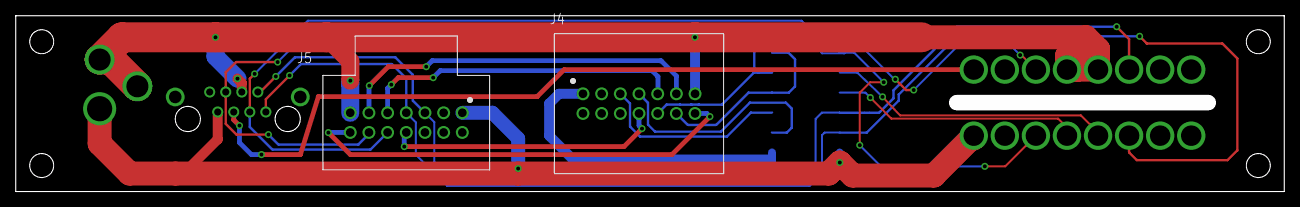
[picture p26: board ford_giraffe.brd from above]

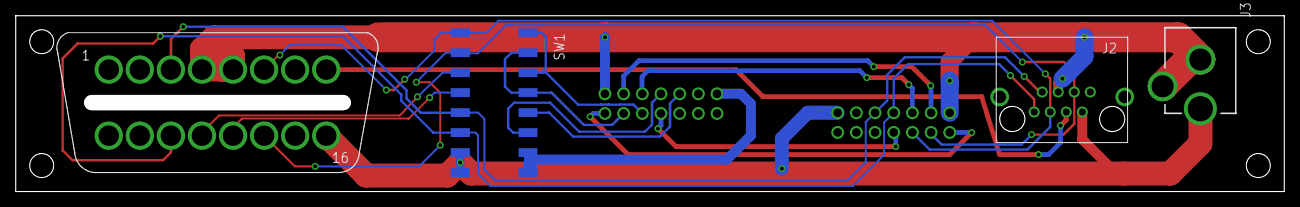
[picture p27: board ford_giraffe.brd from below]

Board: 2 copper layers, 161.3 x 22.4 mm, 7 parts (4 on the bottom side), 18 nets.

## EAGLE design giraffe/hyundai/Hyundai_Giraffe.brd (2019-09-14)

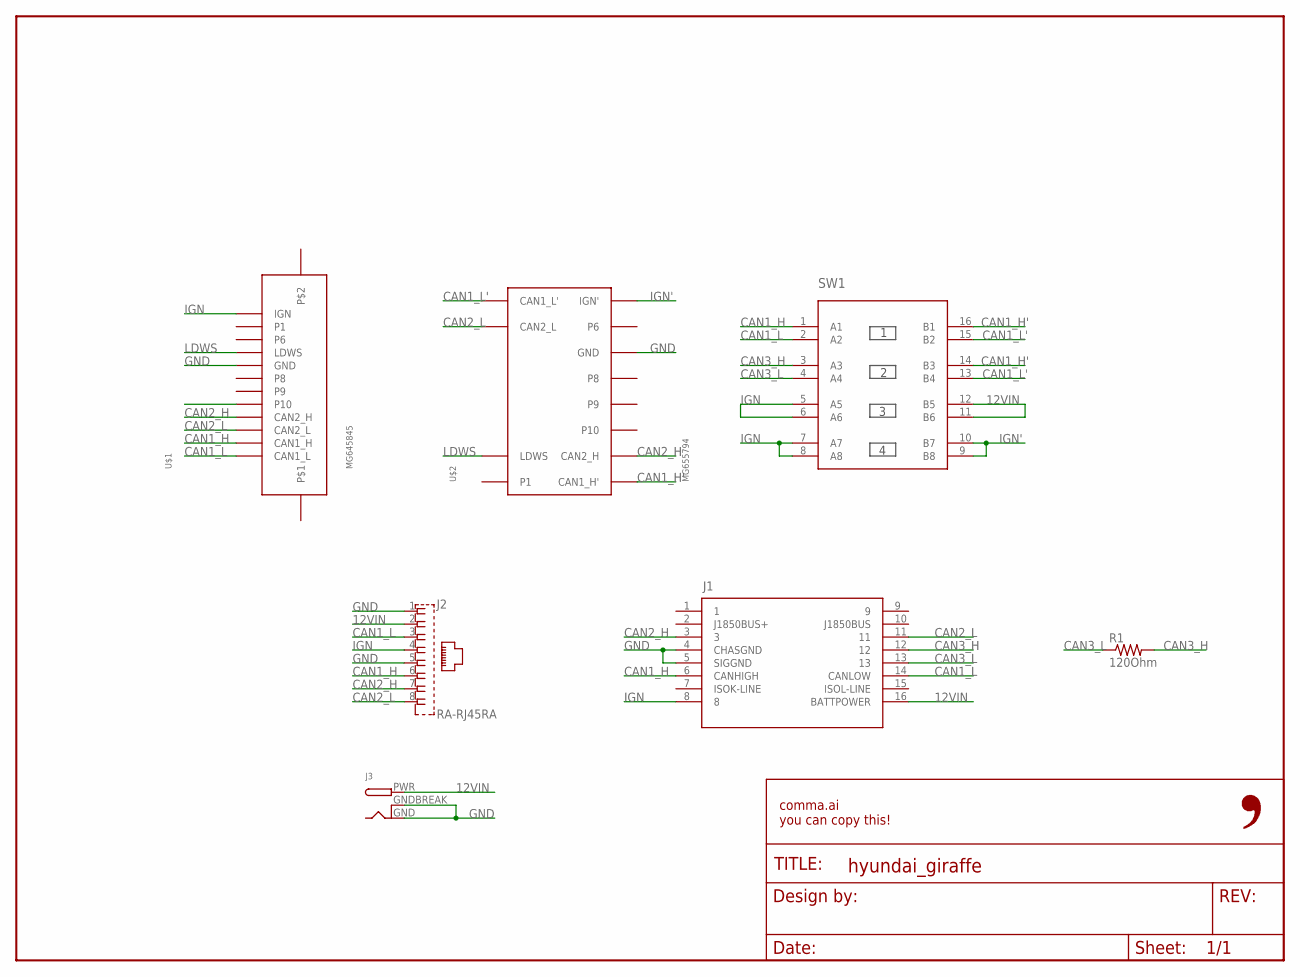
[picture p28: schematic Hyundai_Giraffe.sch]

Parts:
FRAME1: FRAME-LETTER-OPENNO_PACKAGE; DUMMY
J1: OBDII-FEMALE-CUT; OBDII-FEMALE-MIDCUT
J2: RA-RJ45RA; RA-RJ45
J3: DCBARRELPTH; DCJACK_2MM_PTH
R1: 120Ohm; 0603-R
SW1: 4XDPSTSMT; 4-DPST
U$1: MG645845
U$2: MG655794

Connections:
12VIN: J1.16 (BATTPOWER), J2.2, J3.PWR, SW1.11 (B6), SW1.12 (B5)
CAN1_H: J1.6 (CANHIGH), J2.6, SW1.1 (A1), U$1.CAN1_H
CAN1_H': SW1.14 (B3), SW1.16 (B1), U$2.CAN1_H'
CAN1_L: J1.14 (CANLOW), J2.3, SW1.2 (A2), U$1.CAN1_L
CAN1_L': SW1.13 (B4), SW1.15 (B2), U$2.CAN1_L'
CAN2_H: J1.3, J2.7, U$1.CAN2_H, U$2.CAN2_H
CAN2_L: J1.11, J2.8, U$1.CAN2_L, U$2.CAN2_L
CAN3_H: J1.12, R1.2, SW1.3 (A3)
CAN3_L: J1.13, R1.1, SW1.4 (A4)
GND: J1.4 (CHASGND), J1.5 (SIGGND), J2.1, J2.5, J3.GND, J3.GNDBREAK, U$1.GND, U$2.GND
IGN: J1.8, J2.4, SW1.5 (A5), SW1.6 (A6), SW1.7 (A7), SW1.8 (A8), U$1.IGN
IGN': SW1.9 (B8), SW1.10 (B7), U$2.IGN'
LDWS: U$1.LDWS, U$2.LDWS

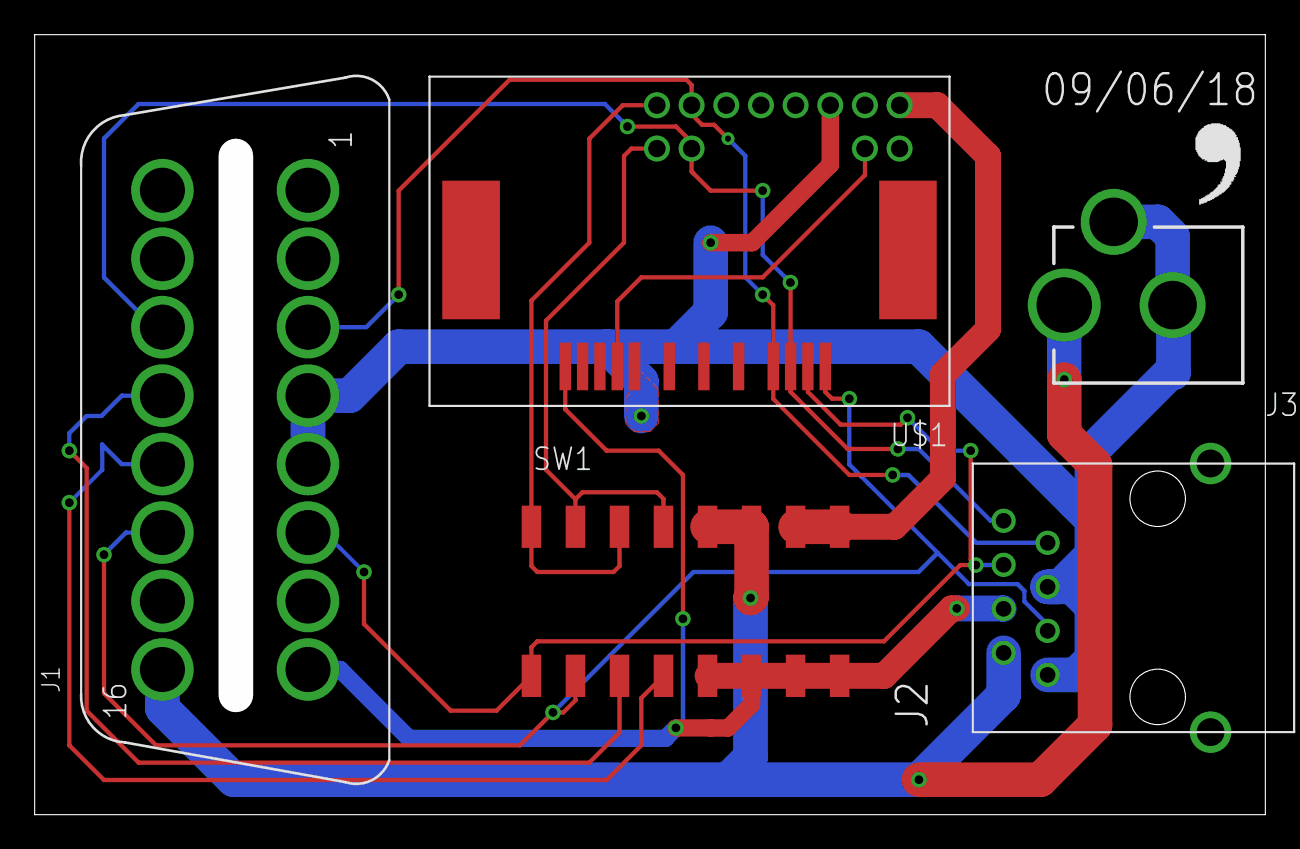
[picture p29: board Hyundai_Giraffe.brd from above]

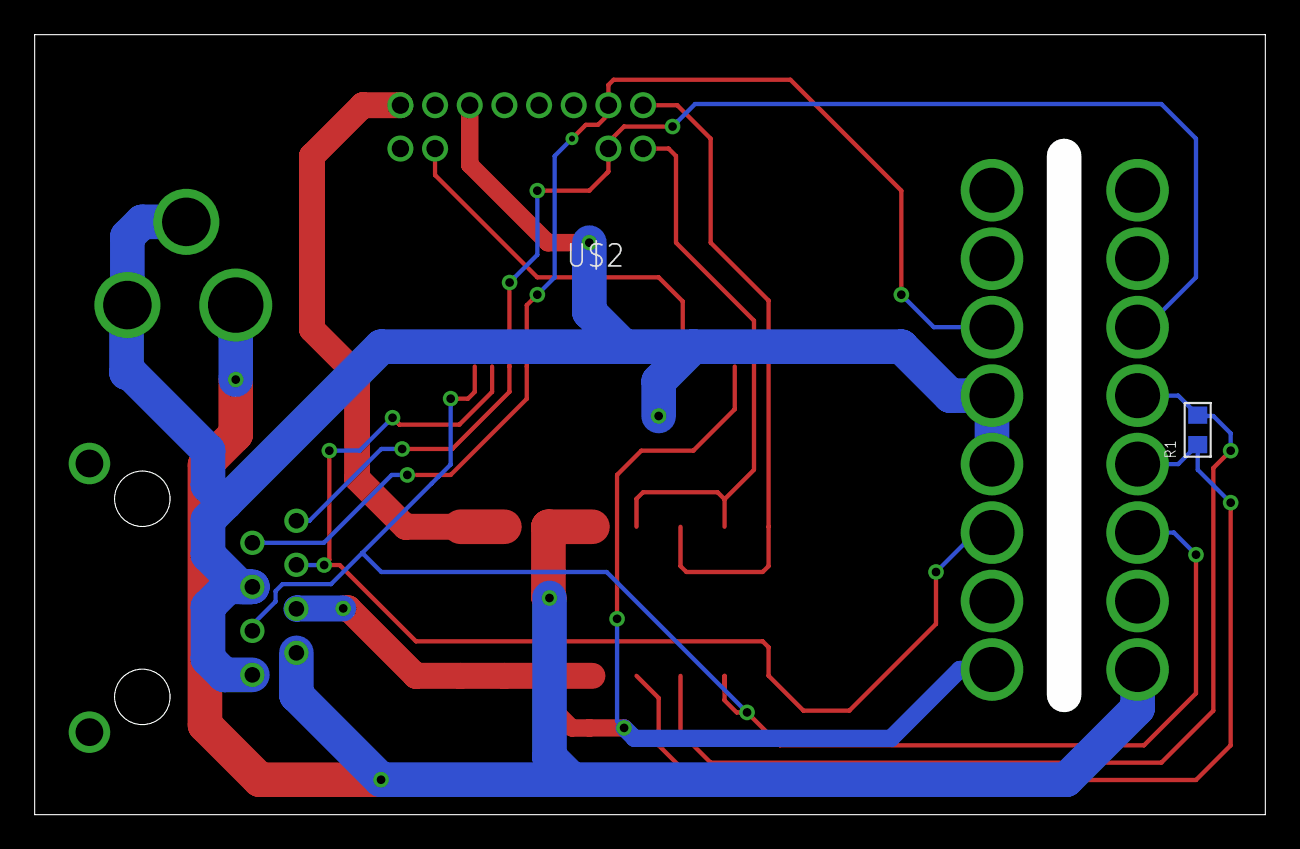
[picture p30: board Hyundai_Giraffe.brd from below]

Board: 2 copper layers, 71.0 x 45.0 mm, 9 parts (2 on the bottom side), 13 nets.

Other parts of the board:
U$3: LOGO

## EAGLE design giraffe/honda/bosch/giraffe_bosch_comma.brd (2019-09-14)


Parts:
D1: DIODE-; DO-214
FRAME1: FRAME-LETTER-OPENNO_PACKAGE; DUMMY
J1: DCBARRELPTH; DCJACK_2MM_PTH
J2: RADAR; BOSCH_12_PIN_FEMALE
J3: OBDII-FEMALE-CUT; OBDII-FEMALE-MIDCUT
J4: VERT_RJ45-ASSMANN; RJ45-VERT
J5: CAM; BOSCH_12_PIN_MALE
SW1: 2XDPST-CTS; 2-DPST

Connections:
12VIN: D1.1 (C), J1.PWR, J3.16 (BATTPOWER), J4.2
CAN_ACC_H: J2.12 (ACC_CAN_H), J3.12, J4.7, SW1.3 (A3)
CAN_ACC_L: J2.6 (ACC_CAN_L), J3.13, J4.8, SW1.4 (A4)
CAN_CAM_H: J3.3, J5.12 (ACC_CAN_H), SW1.6 (B3)
CAN_CAM_L: J3.11, J5.6 (ACC_CAN_L), SW1.5 (B4)
CAN_MAIN_H: J2.11 (F_CAN_H), J3.6 (CANHIGH), J4.6, J5.11 (F_CAN_H)
CAN_MAIN_L: J2.5 (F_CAN_L), J3.14 (CANLOW), J4.3, J5.5 (F_CAN_L)
GND: J1.GND, J1.GNDBREAK, J2.2 (GND), J3.4 (CHASGND), J3.5 (SIGGND), J4.1, J4.5, J5.2 (GND)
IGN: D1.2 (A), J2.1 (IGN), J3.8, J4.4, SW1.1 (A1), SW1.2 (A2)
IGN': J5.1 (IGN), SW1.7 (B2), SW1.8 (B1)
NC3: J2.3 (NC3), J5.3 (NC3)
NC4: J2.4 (NC4), J5.4 (NC4)
NC7: J2.7 (NC7), J5.7 (NC7)
NC8: J2.8 (NC8), J5.8 (NC8)
NC9: J2.9 (NC9), J5.9 (NC9)
NC10: J2.10 (NC10), J5.10 (NC10)

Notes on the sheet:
OBDII
PANDA CAN: 0 - CAN_MAIN 1 - CAN_CAM 2 - CAN_ACC



Board: 2 copper layers, 108.2 x 27.9 mm, 9 parts (2 on the bottom side), 16 nets.

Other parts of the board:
U$1: LOGO

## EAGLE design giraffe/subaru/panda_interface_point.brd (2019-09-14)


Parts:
FRAME1: FRAME-LETTER-OPENNO_PACKAGE; DUMMY
J1: OBDII-FEMALE-CUT; OBDII-FEMALE-MIDCUT
J2: 5018761040
J3: RA-RJ45RA-2; RA-RJ45-2

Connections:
2: J1.2 (J1850BUS+)
9: J1.9
10: J1.10 (J1850BUS)
12VIN: J1.16 (BATTPOWER), J2.P2, J3.2
CAN_ACC_H: J1.3, J2.P6, J3.7
CAN_ACC_L: J1.11, J2.P5, J3.8
CAN_CAM_H: J1.12, J2.P4
CAN_CAM_L: J1.13, J2.P3
CAN_MAIN_H: J1.6 (CANHIGH), J2.P8, J3.6
CAN_MAIN_L: J1.14 (CANLOW), J2.P7, J3.3
GND: J1.4 (CHASGND), J1.5 (SIGGND), J2.P1, J3.1, J3.5
IGN: J1.8, J2.P10, J3.4
IGN/GMLAN: J1.1
K_LIN: J1.7 (ISOK-LINE)
L_LIN: J1.15 (ISOL-LINE), J2.P9



Board: 2 copper layers, 57.3 x 30.1 mm, 5 parts (4 on the bottom side), 10 nets.

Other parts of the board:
U$1: LOGO

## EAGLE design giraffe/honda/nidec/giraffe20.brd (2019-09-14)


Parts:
FRAME1: FRAME-LETTERNO_PACKAGE; DUMMY
J1: MOBILEYERAMALE; 2X10(RA)
J2: MOBILEYEFEMALE; 2X10(JAE_FEMALE)
J3: OBDII-FEMALE-CUT; OBDII-FEMALE-MIDCUT
J4: VERT_RJ45; GLX-S-88M
SW1: 4XDPSTSMT; 4-DPST

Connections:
12VIN: J1.10 (+B_BACKUP), J3.16 (BATTPOWER), J4.2, SW1.8 (A8)
12VIN': J2.10 (+B_BACKUP), SW1.9 (B8)
CAN1_H: J1.2 (CAR-CAN_H), J3.6 (CANHIGH), J4.6, SW1.1 (A1)
CAN1_H': J2.2 (CAR-CAN_H), SW1.14 (B3), SW1.16 (B1)
CAN1_L: J1.13 (CAR-CAN_L), J3.14 (CANLOW), J4.3, SW1.2 (A2)
CAN1_L': J2.13 (CAR-CAN_L), SW1.13 (B4), SW1.15 (B2)
CAN2_H: J1.7 (RADAR-CAN_H), J3.3, J4.7, SW1.5 (A5)
CAN2_H': J2.7 (RADAR-CAN_H), SW1.12 (B5)
CAN2_L: J1.18 (RADAR-CAN_L), J3.11, J4.8, SW1.6 (A6)
CAN2_L': J2.18 (RADAR-CAN_L), SW1.11 (B6)
CAN3_H: J3.12, SW1.3 (A3)
CAN3_L: J3.13, SW1.4 (A4)
GND: J1.14 (GND), J2.14 (GND), J3.4 (CHASGND), J3.5 (SIGGND), J4.1, J4.5
IGN: J1.19 (IG1_OPTION), J3.8, J4.4, SW1.7 (A7)
IGN': J2.19 (IG1_OPTION), SW1.10 (B7)
K_LIN: J1.1 (LKAS2EPS), J2.1 (LKAS2EPS), J3.7 (ISOK-LINE)
LDW_IND: J1.11 (LDW_OFF_IND), J2.11 (LDW_OFF_IND)
LDW_SW: J1.8 (LDW_OFF_SW), J2.8 (LDW_OFF_SW)
L_LIN: J1.12 (EPS2LKAS), J2.12 (EPS2LKAS), J3.15 (ISOL-LINE)
MDX_CANH: J1.6 (NC), J2.6 (NC)
MDX_CANL: J1.17 (NC), J2.17 (NC)

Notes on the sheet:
OBDII
MobilEye Male
MobilEye Female (to Nidec)


Board: 2 copper layers, 100.3 x 31.8 mm, 7 parts (1 on the bottom side), 21 nets.

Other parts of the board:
U$1: LOGO

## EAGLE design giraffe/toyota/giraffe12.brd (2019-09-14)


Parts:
FRAME1: FRAME-LETTERNO_PACKAGE; DUMMY
J1: MOBILEEYE-12FEMALE; 2X6-TE-FEMALE
J2: MOBILEEYE-12MALE; 2X6-TE-RA
J3: OBDII-FEMALE-CUT; OBDII-FEMALE-MIDCUT
J4: RA-RJ45RA; RA-RJ45
J5: DCBARRELPTH; DCJACK_2MM_PTH
R1: 120 ohm; 0603-R
SW1: 4XDPSTSMT; 4-DPST

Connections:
2: J1.2 (NC), J2.2 (NC)
3: J1.3 (NC), J2.3 (NC)
4: J1.4 (NC), J2.4 (NC)
8: J1.8 (NC), J2.8 (NC)
9: J1.9 (NC), J2.9 (NC)
12VIN: J3.16 (BATTPOWER), J4.2, J5.PWR, SW1.11 (B6), SW1.12 (B5)
CAN1_H: J2.5 (CAR_CANH), J3.6 (CANHIGH), J4.6, SW1.1 (A1)
CAN1_H': J1.5 (CAR_CANH), SW1.14 (B3), SW1.16 (B1)
CAN1_L: J2.11 (CAR_CANL), J3.14 (CANLOW), J4.3, SW1.2 (A2)
CAN1_L': J1.11 (CAR_CANL), SW1.13 (B4), SW1.15 (B2)
CAN2_H: J1.6 (RAD_CANH), J2.6 (RAD_CANH), J3.3, J4.7
CAN2_L: J1.12 (RAD_CANL), J2.12 (RAD_CANL), J3.11, J4.8
CAN3_H: J3.12, R1.1, SW1.3 (A3)
CAN3_L: J3.13, R1.2, SW1.4 (A4)
GND: J1.10 (GND), J2.10 (GND), J3.4 (CHASGND), J3.5 (SIGGND), J4.1, J4.5, J5.GND, J5.GNDBREAK
HTR: J2.1 (HTR), SW1.8 (A8)
HTR': J1.1 (HTR), SW1.9 (B8)
IGN: J2.7 (IGN), J3.8, J4.4, SW1.5 (A5), SW1.6 (A6), SW1.7 (A7)
IGN': J1.7 (IGN), SW1.10 (B7)

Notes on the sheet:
OBDII
MobilEye Male
MobilEye Female (to Nidec)



Board: 2 copper layers, 64.8 x 55.2 mm, 9 parts (2 on the bottom side), 19 nets.

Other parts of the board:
U$1: LOGO

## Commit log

2019-06-25 调整打印文件
    [20degMountF2.stl, 22degMountF2.stl, 24degDefaultMountF2.stl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]
2019-06-30 提交挂钩
    [下封口.stl, 修改版挂钩.STL, 原版挂钩.stl]
2019-07-01 添加底座
    [Curved_Mount.SLDPRT, Curved_Mount.STL, GOPRO_底座.stl]
2019-07-03 添加油门和鹿的打印文件
    [BOM.csv, GOPRO_底座.stl, Giraffe_left.stl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]
2021-03-25 change folder names
    translate from chineese to english folder structure
    [FrEON2EM-Left.stl, FrEON2EM-Right.stl, gopro.STL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]
2021-04-15 Renamed files to english names
    [BottomClip.stl, Left Case.STL, Right Case.STL]
2021-04-15 Added Tesla recommended gopro mount
    [Tesla mount 22D_2.15mm_slot.stl]
2021-04-15 Tinkla buddy nordic case readme added
2021-04-15 Tinkla Buddy Nordic Stl's uploaded
    [Tinkla Buddy Nordic_bottom v08.stl, Tinkla Buddy Nordic_top v12.stl]

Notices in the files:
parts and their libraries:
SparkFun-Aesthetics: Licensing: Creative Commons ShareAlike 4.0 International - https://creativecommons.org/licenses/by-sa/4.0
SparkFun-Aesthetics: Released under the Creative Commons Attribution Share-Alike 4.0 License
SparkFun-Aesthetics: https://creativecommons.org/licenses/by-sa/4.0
